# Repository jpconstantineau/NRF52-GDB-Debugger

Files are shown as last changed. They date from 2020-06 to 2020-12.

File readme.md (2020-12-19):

# NRF52-GDB-DEBUGGER

## Why?

### Software
This SWD Programmer gets rid of intermediate programs like OpenOCD, STLink server or Segger J-Link.  You just start GNU Debugger (GDB) and select the virtual com port offered by the programmer as your extended remote target.  This means that you only need arm-none-eabi-gdb which is part of the GNU Arm Embedded Toolchain and do not need to install any other software on your computer.  It also means that it's compatible with Windows, Linux and MacOS.

### Hardware
Hardware is compatible with the Version 1 of the [Black Magic Probe](https://github.com/blacksphere/blackmagic). Schematic of the programmer is [here](https://github.com/jpconstantineau/NRF52-GDB-Debugger/blob/master/hardware/bmp/schematic.pdf).  Although you can use an inexpensive Bluepill board and flash the BMP firmware yourself, this programmer adds these features:

* Compatible with native BMP firmware
* Supports 1.8V up to 3.3V targets (TXS0108E level shifter)
* Can provide 3.3V to the target (Mosfet switch)
* 10 pin 0.1" header compatible with the standard Arm Cortex SWD header, including the [TC2050](https://www.tag-connect.com/product/tc2050-idc-nl-10-pin-no-legs-cable-with-ribbon-connector)
* 4 pin 0.1" SWD header, compatible with the BlueMicro840 and BlueMacro840 SWD pads (No need for extra cables to flash bootloader to these boards).
* USB-C Connector

## Firmware
You can follow the instructions on the [BMP Wiki](https://github.com/blacksphere/blackmagic/wiki/Upgrading-Firmware) to update the firmware on the programmer.  You can use the latest [firmware](https://github.com/blacksphere/blackmagic/releases/) and upload the blackmagic-native.bin file contained in the tar.gz file.

On Windows, you may need [Zadig](https://github.com/pbatard/libwdi/releases/download/b730/zadig-2.5.exe) in order for the DFU Utility to detect the programmer.

## Programming the nRF52 using this programmer.

As a starting point, have a look [here](https://bluetun.serverbox.ch/2020/01/10/flashing-the-nrf52840-with-a-blackmagic-probe-swd-jtag-programmer/)

The [Community Add-on to the Adafruit_nRF52_Arduino Board Support Package](https://github.com/jpconstantineau/Community_nRF52_Arduino) has included the Black Magic Probe to the Arduino IDE so that it can be used to program the bootloader. See it in action [here](https://youtu.be/hIclx-_i-jQ)

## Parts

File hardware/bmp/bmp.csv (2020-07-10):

Comment | Designator | Footprint | LCSC | LCSC
10uF | C1,C2 | Capacitor_SMD:C_0603_1608Metric |  | C19702
22pF | C4,C3 | Capacitor_SMD:C_0603_1608Metric |  | C1653
100nF | C5,C6,C7,C8 | Capacitor_SMD:C_0603_1608Metric |  | C14663
Green - 19-217/GHC-YR1S2/3T | D1 | LED_SMD:LED_0603_1608Metric |  | C72043
Red - KT-0603R | D2 | LED_SMD:LED_0603_1608Metric |  | C2286
Yellow - 19-213/Y2C-CQ2R2L/3T(CY) | D3,D4 | LED_SMD:LED_0603_1608Metric |  | C72038
USB_C_Receptacle | J1 | footprints:HRO-TYPE-C-31-M-12-C165948
TC2050-IDC | J2 | Connector:Tag-Connect_TC2050-IDC-NL_2x05_P1.27mm_Vertical
Conn_02x05_Odd_Even | J3 | Connector_PinHeader_2.54mm:PinHeader_2x05_P2.54mm_Vertical
Conn_01x03 | J4 | Connector_PinHeader_2.54mm:PinHeader_1x03_P2.54mm_Vertical
Conn_01x04 | J5 | Connector_PinHeader_2.54mm:PinHeader_1x04_P2.54mm_Vertical
MountingHole | MH1,MH2 | kbd:HOLE_JLCPCBA
SI2301CDS-T1-GE3 | Q1 | Package_TO_SOT_SMD:SOT-23 |  | C10487
5k1 | R1,R2 | Resistor_SMD:R_0603_1608Metric |  | C23186
1k0 | R10,R9,R8,R7 | Resistor_SMD:R_0603_1608Metric |  | C21190
10k | R11,R14,R15 | Resistor_SMD:R_0603_1608Metric |  | C25804
4k7 | R12,R13 | Resistor_SMD:R_0603_1608Metric |  | C23162
100R | R16,R17,R18,R19,R20,R21 | Resistor_SMD:R_0603_1608Metric |  | C22775
22R | R3,R4 | Resistor_SMD:R_0603_1608Metric |  | C23345
1k5 | R5 | Resistor_SMD:R_0603_1608Metric |  | C22843
SW_Push | SW2 | footprints:SW_TACT_TS-1145A_C318904 |  | C318904
TestPoint_Probe | TP1 | footprints:KB_BlueMicro
AP2112K-3.3 | U1 | Package_TO_SOT_SMD:SOT-23-5 |  | C51118
STM32F103CBTx | U2 | Package_QFP:LQFP-48_7x7mm_P0.5mm |  | C8304
TXS0108EPWR | U3 | footprints:TSSOP20-0.65-6.5X4.4MM |  | C17206
8MHz | X1 | Crystal:Crystal_SMD_5032-2Pin_5.0x3.2mm |  | C115962

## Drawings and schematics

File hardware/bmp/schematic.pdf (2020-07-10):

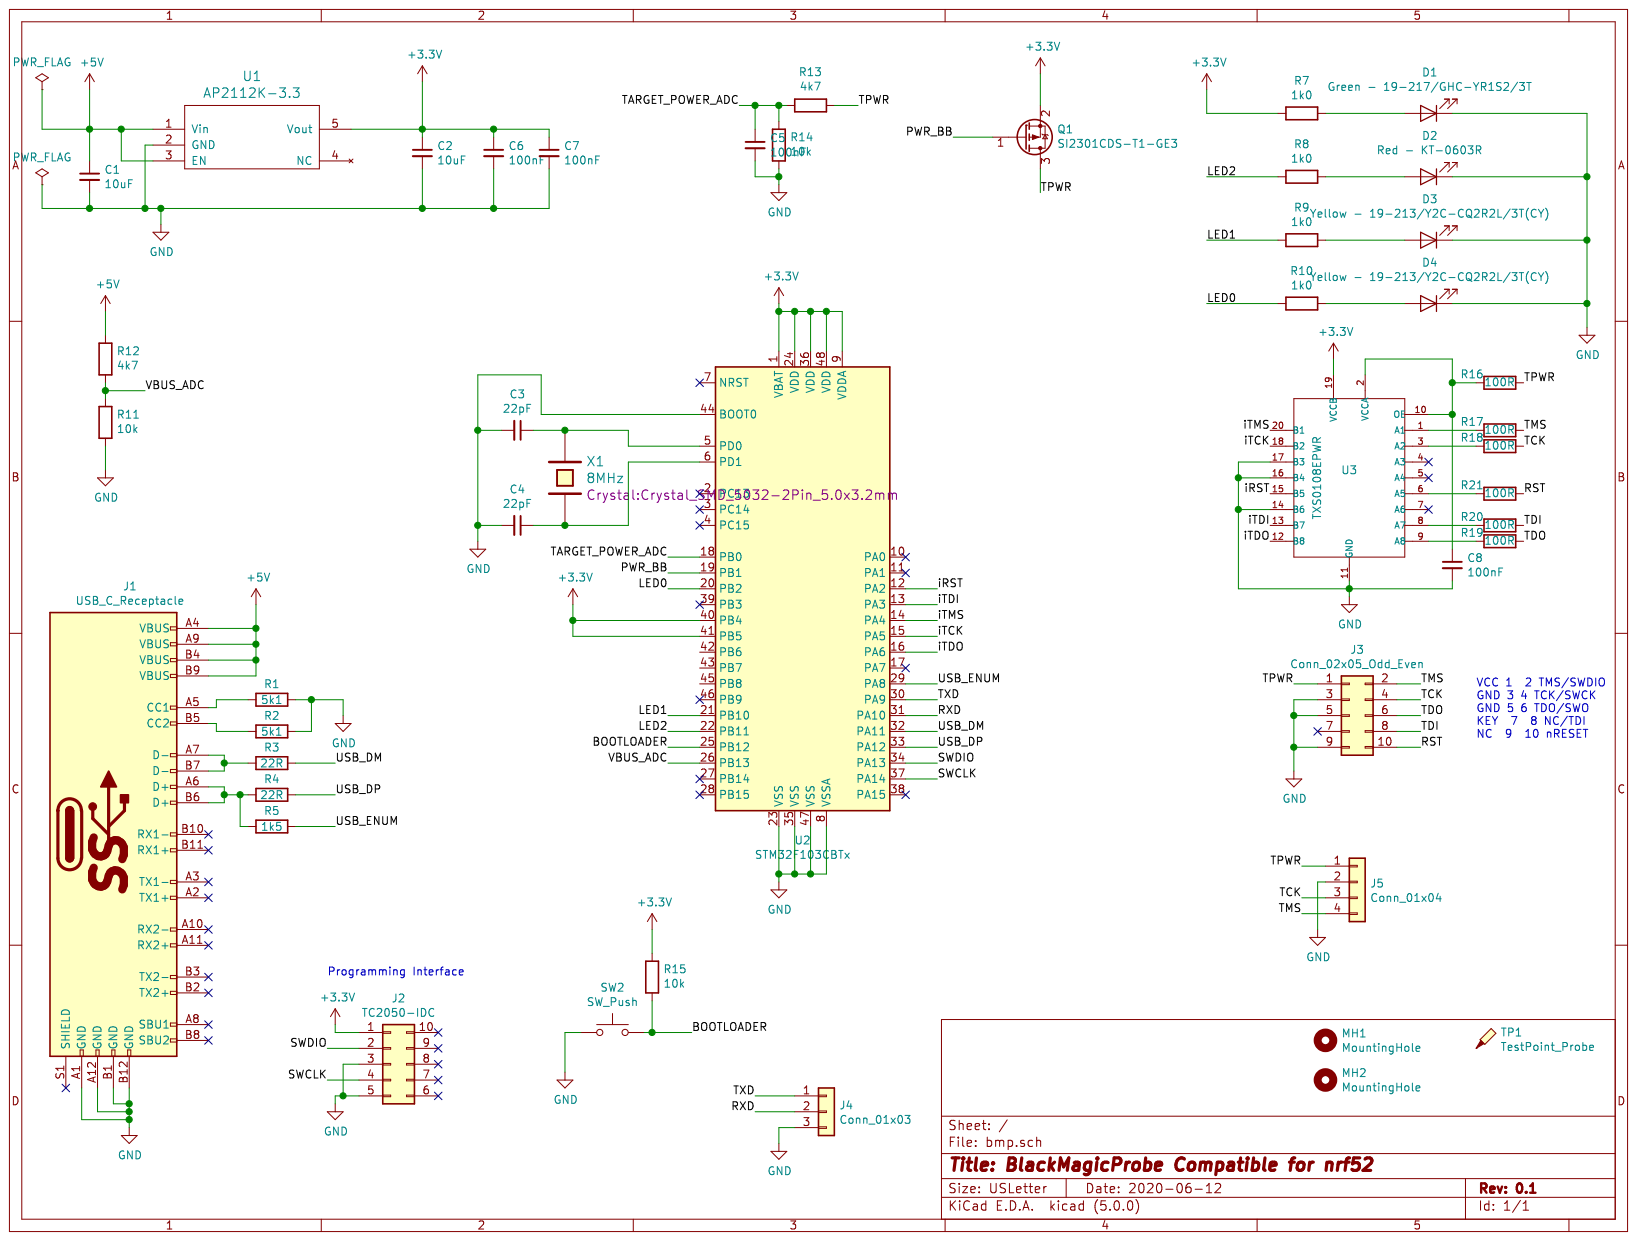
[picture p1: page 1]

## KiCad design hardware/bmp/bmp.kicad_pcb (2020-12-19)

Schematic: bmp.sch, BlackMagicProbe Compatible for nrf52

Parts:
C1, C2: 10uF; C_0603_1608Metric; LCSC C19702
C3, C4: 22pF; C_0603_1608Metric; LCSC C1653
C5, C6, C7, C8: 100nF; C_0603_1608Metric; LCSC C14663
D1: Green - 19-217/GHC-YR1S2/3T; LED_0603_1608Metric; LCSC C72043
D2: Red - KT-0603R; LED_0603_1608Metric; LCSC C2286
D3, D4: Yellow - 19-213/Y2C-CQ2R2L/3T(CY); LED_0603_1608Metric; LCSC C72038
J1: USB_C_Receptacle; HRO-TYPE-C-31-M-12-C165948
J2: TC2050-IDC; Tag-Connect_TC2050-IDC-NL_2x05_P1.27mm_Vertical
J3: Conn_02x05_Odd_Even; PinHeader_2x05_P2.54mm_Vertical
J4: Conn_01x03; PinHeader_1x03_P2.54mm_Vertical
J5: Conn_01x04; PinHeader_1x04_P2.54mm_Vertical
MH1, MH2: MountingHole; HOLE_JLCPCBA
Q1: SI2301CDS-T1-GE3; SOT-23; LCSC C10487
R1, R2: 5k1; R_0603_1608Metric; LCSC C23186
R3, R4: 22R; R_0603_1608Metric; LCSC C23345
R5: 1k5; R_0603_1608Metric; LCSC C22843
R7, R8, R9, R10: 1k0; R_0603_1608Metric; LCSC C21190
R11, R14, R15: 10k; R_0603_1608Metric; LCSC C25804
R12, R13: 4k7; R_0603_1608Metric; LCSC C23162
R16, R17, R18, R19, R20, R21: 100R; R_0603_1608Metric; LCSC C22775
SW2: SW_Push; SW_TACT_TS-1145A_C318904; LCSC C318904
TP1: TestPoint_Probe; KB_BlueMicro
U1: AP2112K-3.3; SOT-23-5; LCSC C51118
U2: STM32F103CBTx; LQFP-48_7x7mm_P0.5mm; LCSC C8304
U3: TXS0108EPWR; TSSOP20-0.65-6.5X4.4MM; LCSC C17206
X1: 8MHz; Crystal_SMD_5032-2Pin_5.0x3.2mm; LCSC C115962

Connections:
+3V3: C2.1, C6.1, C7.1, J2.1, Q1.2 (S), R7.2, R15.2, U1.5, U2.1 (VBAT), U2.9 (VDDA), U2.24 (VDD), U2.36 (VDD), U2.40 (PB4), U2.41 (PB5), U2.48 (VDD), U3.19
+5V: C1.1, J1.A4, R12.2, U1.1, U1.3
/BOOTLOADER: R15.1, SW2.2, U2.25 (PB12)
/LED0: R10.2, U2.20 (PB2)
/LED1: R9.2, U2.21 (PB10)
/LED2: R8.2, U2.22 (PB11)
/PWR_BB: Q1.1 (G), U2.19 (PB1)
/RST: J3.10, R21.2
/RXD: J4.2, U2.31 (PA10)
/SWCLK: J2.4, U2.37 (PA14)
/SWDIO: J2.2, U2.34 (PA13)
/TARGET_POWER_ADC: C5.1, R13.1, R14.2, U2.18 (PB0)
/TCK: J3.4, J5.3, R18.2
/TDI: J3.8, R20.2
/TDO: J3.6, R19.2
/TMS: J3.2, J5.4, R17.2
/TPWR: J3.1, J5.1, Q1.3 (D), R13.2, R16.2
/TXD: J4.1, U2.30 (PA9)
/USB_DM: R3.1, U2.32 (PA11)
/USB_DP: R4.1, U2.33 (PA12)
/USB_ENUM: R5.1, U2.29 (PA8)
/VBUS_ADC: R11.2, R12.1, U2.26 (PB13)
/iRST: U2.12 (PA2), U3.15
/iTCK: U2.15 (PA5), U3.18
/iTDI: U2.13 (PA3), U3.13
/iTDO: U2.16 (PA6), U3.12
/iTMS: U2.14 (PA4), U3.20
unnamed: C3.1, U2.5 (PD0), X1.1
unnamed: C4.1, U2.6 (PD1), X1.2
unnamed: C8.1, R16.1, U3.2, U3.10
unnamed: D1.2, R7.1
unnamed: D2.2, R8.1
unnamed: D3.2, R9.1
unnamed: D4.2, R10.1
unnamed: J1.A5, R1.2
unnamed: J1.A6, J1.B6, R4.2, R5.2
unnamed: J1.A7, J1.B7, R3.2
unnamed: J1.B5, R2.2
unnamed: R17.1, U3.1
unnamed: R18.1, U3.3
unnamed: R19.1, U3.9
unnamed: R20.1, U3.8
unnamed: R21.1, U3.6

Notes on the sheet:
VCC 1 2 TMS/SWDIO GND 3 4 TCK/SWCK GND 5 6 TDO/SWO KEY 7 8 NC/TDI NC 9 10 nRESET
Programming Interface

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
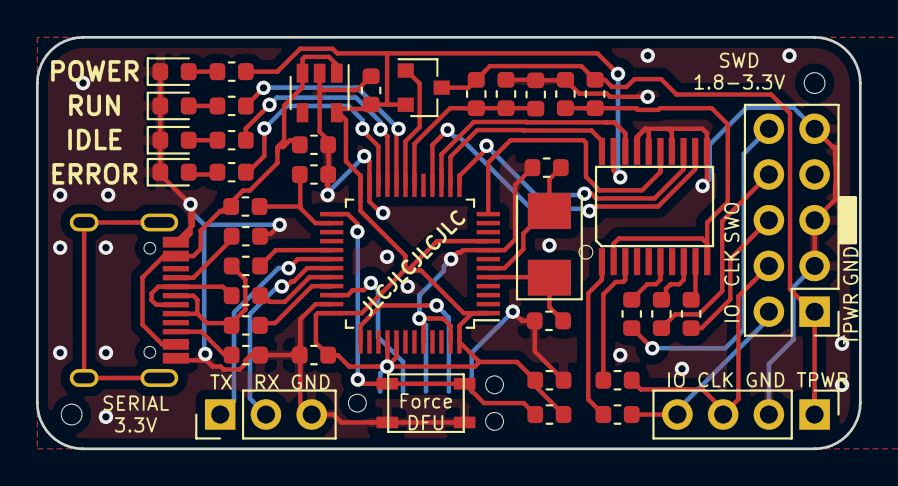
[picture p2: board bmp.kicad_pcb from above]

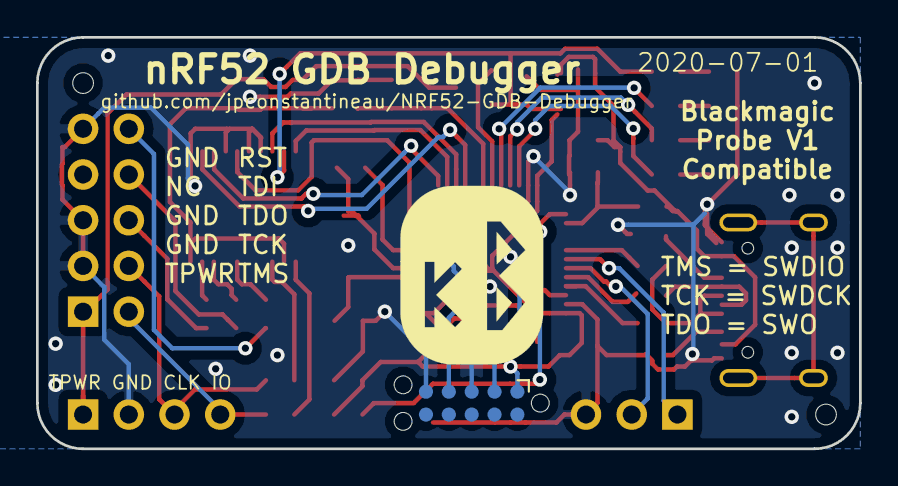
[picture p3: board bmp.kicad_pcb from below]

Board: 2 copper layers, 45.7 x 22.9 mm, 46 parts (2 on the bottom side), 44 nets.

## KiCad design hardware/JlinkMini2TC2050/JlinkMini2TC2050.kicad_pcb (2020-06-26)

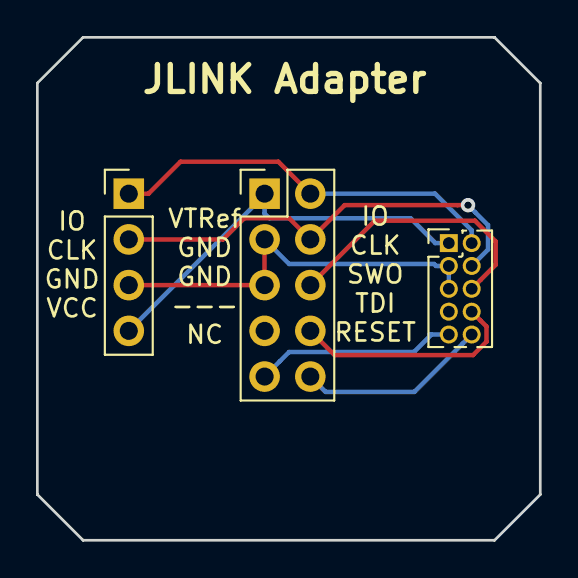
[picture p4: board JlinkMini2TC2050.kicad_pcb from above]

Board: 2 copper layers, 27.9 x 27.9 mm, 3 parts (0 on the bottom side), 8 nets.

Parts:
J1: Conn_02x05_Odd_Even; PinHeader_2x05_P1.27mm_Vertical
J2: Conn_02x05_Odd_Even; PinHeader_2x05_P2.54mm_Vertical
J3: Conn_01x04; PinHeader_1x04_P2.54mm_Vertical

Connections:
GND: J1.3, J1.5, J2.3, J2.5, J3.3
NC: J1.9, J2.9
SWDCLK: J1.4, J2.4, J3.2
SWDIO: J1.2, J2.2, J3.1
SWO: J1.6, J2.6
TDI: J1.8, J2.8
VTRef: J1.1, J2.1, J3.4
nRESET: J1.10, J2.10

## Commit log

2020-07-10 updated with 2019 gdb
    [bmp-B.Cu.gbr, bmp-B.Mask.gbr, bmp-B.Paste.gbr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]
2020-12-19 update to the scripts
    [bmp-B.Cu.gbr, bmp-B.Mask.gbr, bmp-B.Paste.gbr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]
